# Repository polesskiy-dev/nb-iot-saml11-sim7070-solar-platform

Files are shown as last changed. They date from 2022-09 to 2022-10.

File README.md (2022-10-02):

# NB IoT platform

### Based on:
* MCU: Microchip SAML11
* GSM, GPS: SIMCom SIM7070
* Power: 2V Solar panel or DC 5V, MPPT harvester, 1xLiFePO4 18650 

### Hardware features:
* Sensors IN: 
  * 2xPulse, 3V3-48V tolerant, optocouple galvanic isolation. Supports NPN, PNP
  * 1xADC, 1V2-48V tolerant
  * 2x4 wires: USART, LIN client, I2C client/host, SPI client/host, RS485 (3V3), 3V3-5V tolerant, buffered
* Sensors power OUT: 3V3, 12V or self-powered
* Power: 1V5-2V5 Solar MPPT Harvester or DC 5V, LiFePO4/Li-ion charger, reverse polarity protection
* [ ] power consumption values plot

### Software features:
* [ ] AWS integration
* [ ] MQTTs
* [ ] I2C BME280 temperature/humidity/pressure sensor support

### Schematics:


### Board:

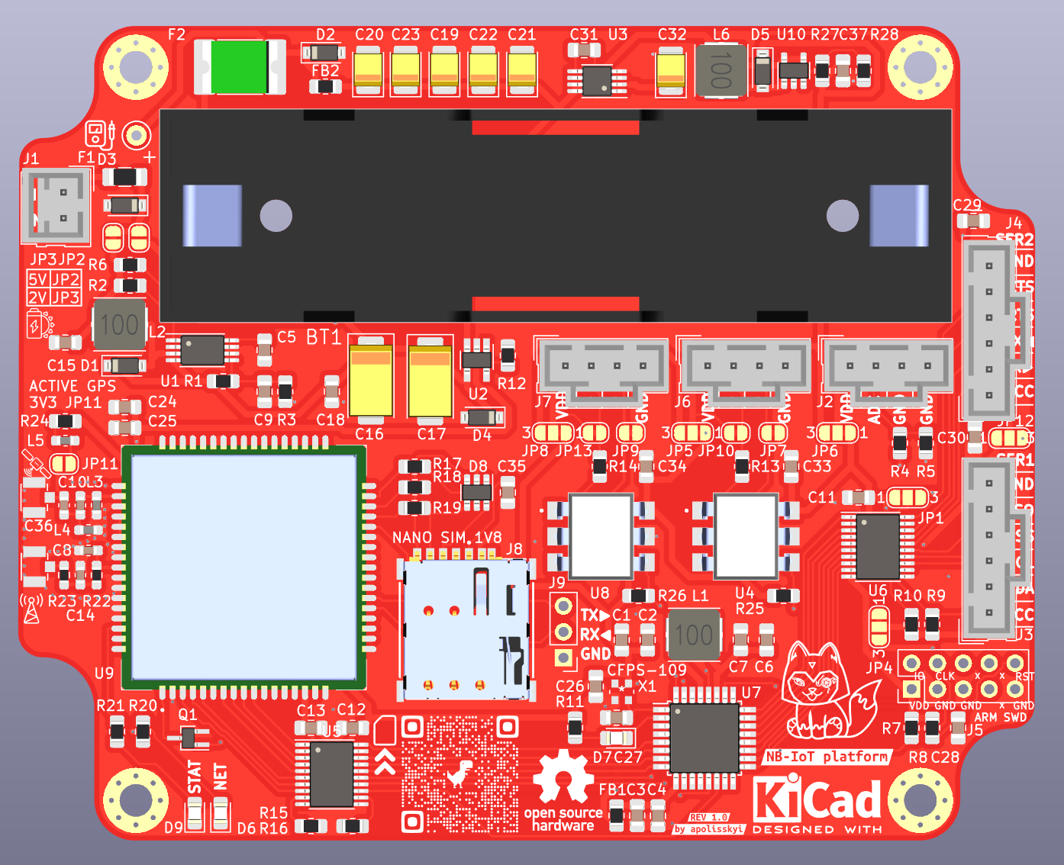
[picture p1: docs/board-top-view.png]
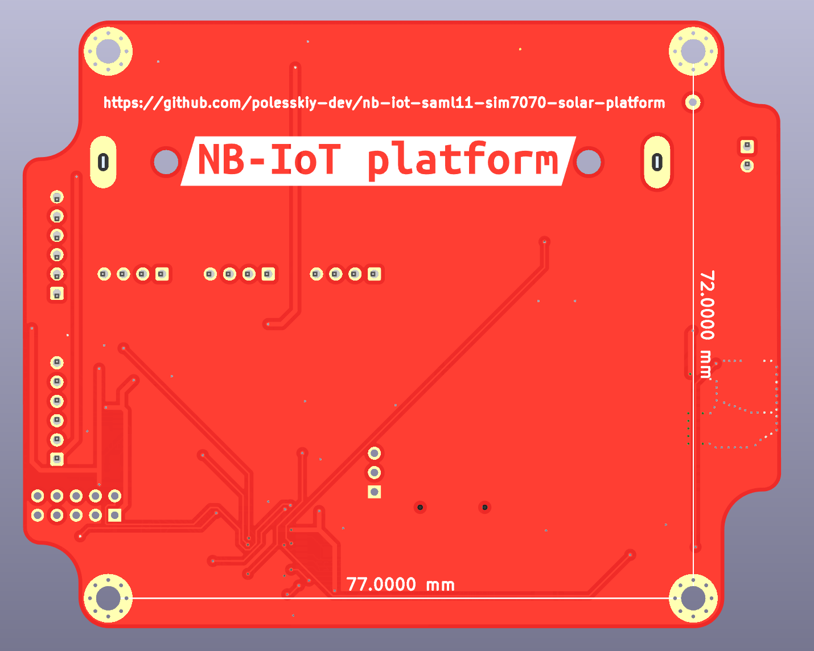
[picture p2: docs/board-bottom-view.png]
 

### Enclosure:
Gainta G113

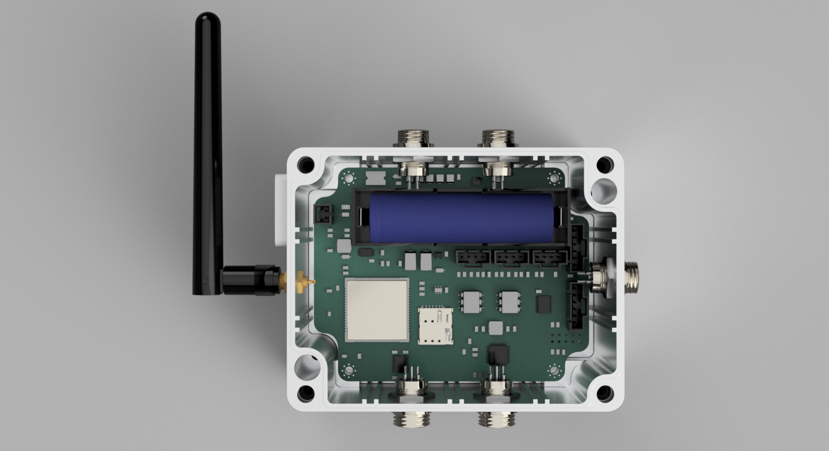
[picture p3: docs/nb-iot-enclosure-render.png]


### BOM:
[Interactive BOM](https://polesskiy-dev.github.io/nb-iot-saml11-sim7070-solar-platform/bom/ibom.html)

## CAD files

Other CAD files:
hardware/nb-iot-saml11-sim7070-solar-platform-G113-v17.f3d

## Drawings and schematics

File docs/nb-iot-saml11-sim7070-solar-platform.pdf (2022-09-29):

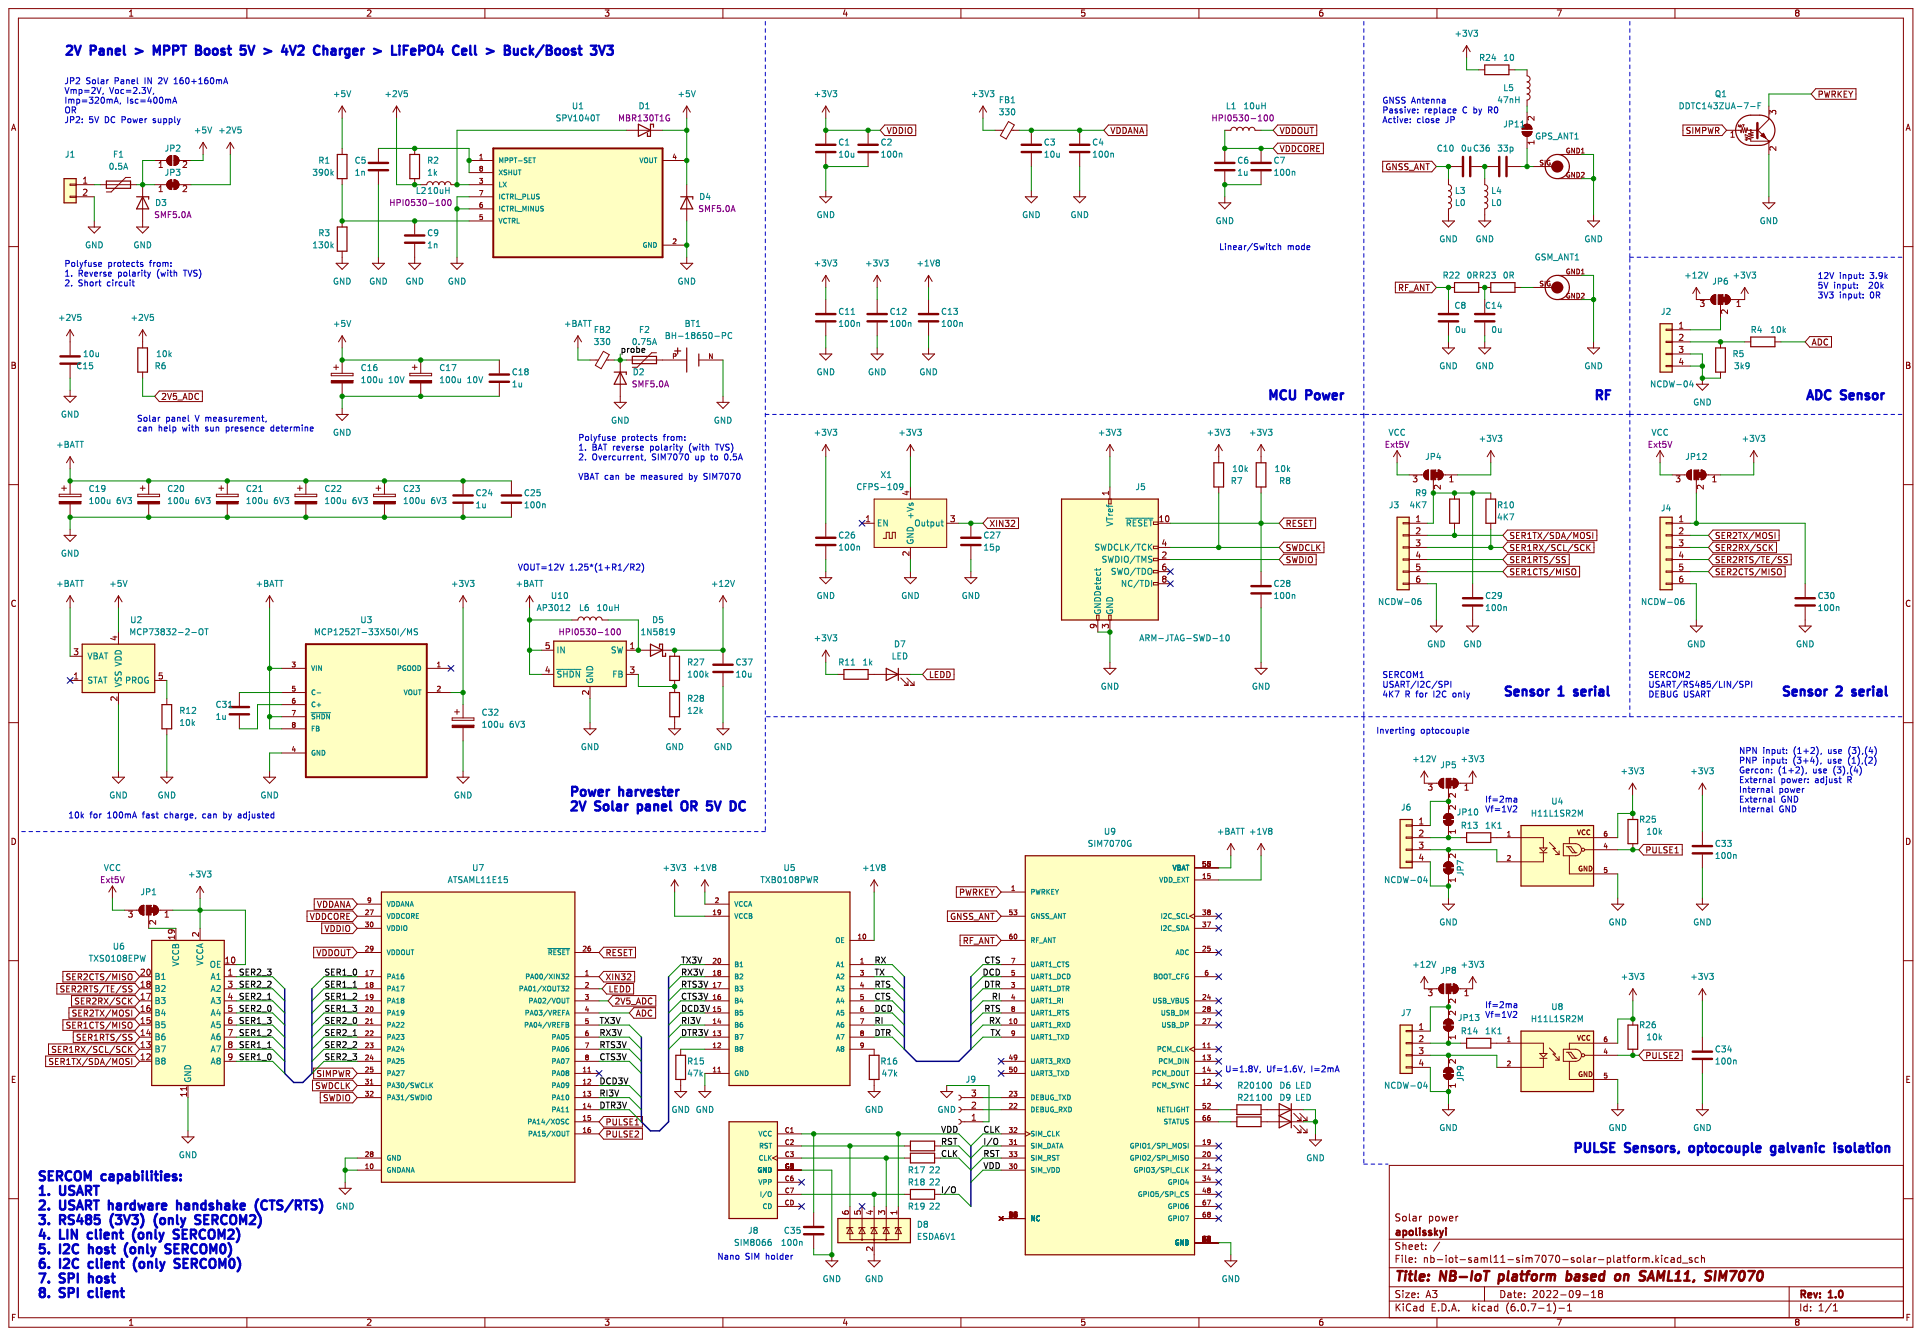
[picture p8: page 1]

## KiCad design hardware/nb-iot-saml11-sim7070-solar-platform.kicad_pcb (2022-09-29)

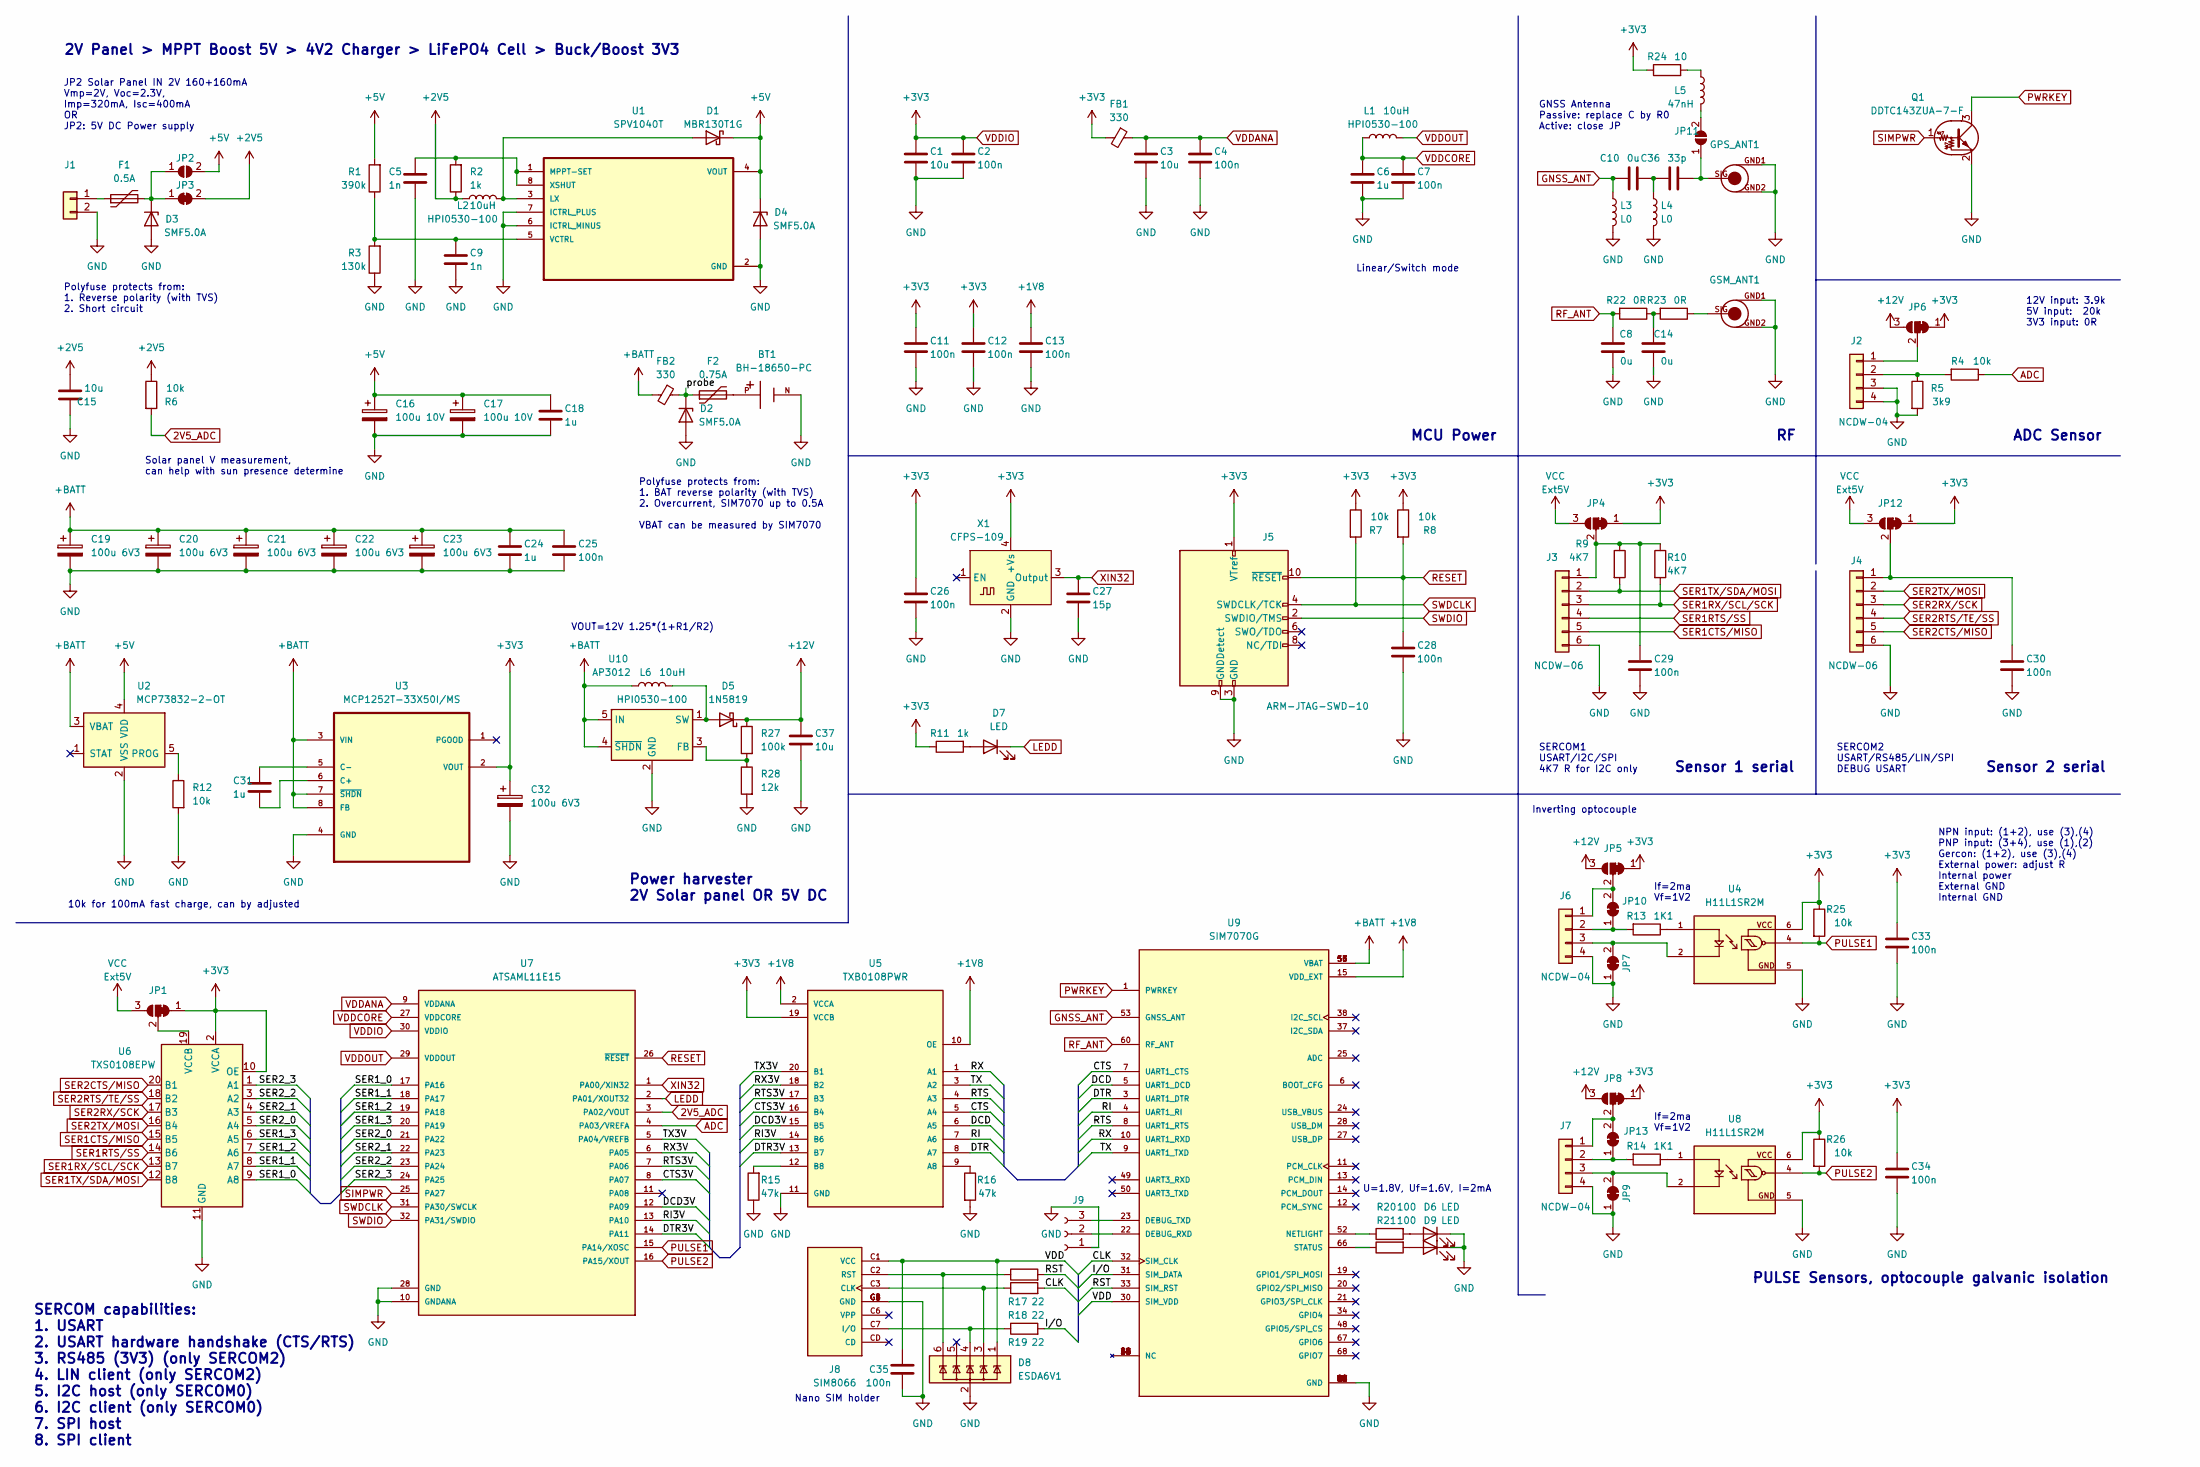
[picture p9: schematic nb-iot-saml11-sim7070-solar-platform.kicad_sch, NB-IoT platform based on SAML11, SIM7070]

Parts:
BT1: BH-18650-PC; BAT_BH-18650-PC; PARTREV 05/17/19
C1, C3, C15, C37: 10u; C_0805_2012Metric_Pad1.18x1.45mm_HandSolder
C2, C4, C7, C11, C12, C13, C25, C26, C28, C29, C30, C33, C34, C35: 100n; C_0805_2012Metric_Pad1.18x1.45mm_HandSolder
C5, C9: 1n; C_0805_2012Metric_Pad1.18x1.45mm_HandSolder
C6, C18, C24, C31: 1u; C_0805_2012Metric_Pad1.18x1.45mm_HandSolder
C8, C10, C14: 0u; C_0603_1608Metric_Pad1.08x0.95mm_HandSolder
C16, C17: 100u 10V; CP_EIA-7343-31_Kemet-D_Pad2.25x2.55mm_HandSolder; PARTNUMBER T491D107K010AT
C19, C20, C21, C22, C23, C32: 100u 6V3; CP_EIA-3528-21_Kemet-B_Pad1.50x2.35mm_HandSolder; PARTNUMBER TAJB107K006RNJ
C27: 15p; C_0805_2012Metric_Pad1.18x1.45mm_HandSolder
C36: 33p; C_0603_1608Metric_Pad1.08x0.95mm_HandSolder
D1: D_Schottky; D_SOD-123; PARTNUMBER MBR130T1G
D2, D3, D4: D_Zener; D_SOD-123; PARTNUMBER SMF5.0A
D5: 1N5819; D_SOD-123
D6, D7, D9: LED; LED_0805_2012Metric_Pad1.15x1.40mm_HandSolder
D8: ESDA6V1; SOT-23-6
F1: 0.5A; Fuse_1206_3216Metric_Pad1.42x1.75mm_HandSolder; PARTNUMBER SMD1206P050TF
F2: 0.75A; Fuse_2920_7451Metric_Pad2.10x5.45mm_HandSolder; PARTNUMBER 0ZCF0075FF2C
FB1, FB2: 330; R_0805_2012Metric_Pad1.20x1.40mm_HandSolder
GPS_ANT1: U.FL-R-SMT-1; GHI-CONNECTORS_U.FL-R-SMT-1
GSM_ANT1: U.FL-R-SMT-1; GHI-CONNECTORS_U.FL-R-SMT-1
J1: Conn_01x02; Molex_SL_171971-0002_1x02_P2.54mm_Vertical
J2, J6, J7: NCDW-04; Molex_SL_171971-0004_1x04_P2.54mm_Vertical
J3, J4: NCDW-06; Molex_SL_171971-0006_1x06_P2.54mm_Vertical
J5: ARM-JTAG-SWD-10; PinHeader_2x05_P2.54mm_Vertical
J8: SIM8066; GCT_SIM8066-6-1-14-01-A_REVA; PARTREV REVA
J9: Conn_01x03_Female; PinHeader_1x03_P2.54mm_Vertical
JP1, JP4, JP5, JP6, JP8, JP12: SolderJumper_3_Bridged12; SolderJumper-3_P1.3mm_Bridged12_RoundedPad1.0x1.5mm_NumberL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
JP2, JP11: SolderJumper_2_Open; SolderJumper-2_P1.3mm_Open_RoundedPad1.0x1.5mm
JP3, JP7, JP9, JP10, JP13: SolderJumper_2_Bridged; SolderJumper-2_P1.3mm_Bridged_RoundedPad1.0x1.5mm
L1, L2, L6: 10uH; L_Taiyo-Yuden_MD-5050; PARTNUMBER HPI0530-100
L3, L4: L0; L_0603_1608Metric_Pad1.05x0.95mm_HandSolder
L5: 47nH; L_0603_1608Metric_Pad1.05x0.95mm_HandSolder
Q1: DDTC143ZUA-7-F; SOT-323_SC-70_Handsoldering
R1: 390k; R_0805_2012Metric_Pad1.20x1.40mm_HandSolder
R2, R11: 1k; R_0805_2012Metric_Pad1.20x1.40mm_HandSolder
R3: 130k; R_0805_2012Metric_Pad1.20x1.40mm_HandSolder
R4, R6, R7, R8, R12, R25, R26: 10k; R_0805_2012Metric_Pad1.20x1.40mm_HandSolder
R5: 3k9; R_0805_2012Metric_Pad1.20x1.40mm_HandSolder
R9, R10: 4K7; R_0805_2012Metric_Pad1.20x1.40mm_HandSolder
R13, R14: 1K1; R_0805_2012Metric_Pad1.20x1.40mm_HandSolder
R15, R16: 47k; R_0805_2012Metric_Pad1.20x1.40mm_HandSolder
R17, R18, R19: 22; R_0805_2012Metric_Pad1.20x1.40mm_HandSolder
R20, R21: 100; R_0805_2012Metric_Pad1.20x1.40mm_HandSolder
R22, R23: 0R; R_0603_1608Metric_Pad0.98x0.95mm_HandSolder
R24: 10; R_0805_2012Metric_Pad1.20x1.40mm_HandSolder
R27: 100k; R_0805_2012Metric_Pad1.20x1.40mm_HandSolder
R28: 12k; R_0805_2012Metric_Pad1.20x1.40mm_HandSolder
U1: SPV1040T; TSSOP-8_4.4x3mm_P0.65mm; PARTREV 7
U2: MCP73832-2-OT; SOT-23-5_HandSoldering
U3: MCP1252T-33X50I/MS; MSOP-8_3x3mm_P0.65mm; MPN MCP1252T-33X50I/MS
U4, U8: H11L1SR2M; IC_H11L1SR2M; PARTREV 3
U5: TXB0108PWR; TSSOP-20_4.4x6.5mm_P0.65mm; PARTREV H
U6: TXS0108EPW; TSSOP-20_4.4x6.5mm_P0.65mm
U7: ATSAML11E15; TQFP-32_7x7mm_P0.8mm; PARTREV G
U9: SIM7070G; MODULE_SIM7070G; PARTREV V1.03
U10: AP3012; SOT-23-5
X1: CFPS-109

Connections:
2V5_ADC: R6.2, U7.3 (PA02/VOUT)
+1V8: C13.1, U5.2 (VCCA), U5.10 (OE), U9.15 (VDD_EXT)
+2V5: C15.2, JP3.2 (B), L2.1, R2.1, R6.1
+5V: C16.1, C17.1, C18.1, D1.1 (K), D4.1 (K), JP2.2 (B), R1.2, U1.4 (VOUT), U2.4 (VDD)
+12V: C37.1, D5.1 (K), JP5.3 (B), JP6.3 (B), JP8.3 (B), R27.1
+BATT: C19.1, C20.1, C21.1, C22.1, C23.1, C24.1, C25.1, FB2.2, L6.1, U2.3 (VBAT), U3.3 (VIN), U3.7 (~SHDN), U3.8 (FB), U9.55 (VBAT), U9.56 (VBAT), U9.57 (VBAT), U10.4 (~SHDN), U10.5 (IN)
/CLK: R18.2, U9.32 (SIM_CLK)
/CTS: U5.5 (A4), U9.7 (UART1_CTS)
/CTS3V: U5.16 (B4), U7.8 (PA07)
/DCD: U5.6 (A5), U9.5 (UART1_DCD)
/DCD3V: U5.15 (B5), U7.12 (PA09)
/DTR: U5.8 (A7), U9.3 (UART1_DTR)
/DTR3V: U5.13 (B7), U7.14 (PA11)
/I/O: R19.2, U9.31 (SIM_DATA)
/RI: U5.7 (A6), U9.4 (UART1_RI)
/RI3V: U5.14 (B6), U7.13 (PA10)
/RST: R17.2, U9.33 (SIM_RST)
/RTS: U5.4 (A3), U9.8 (UART1_RTS)
/RTS3V: U5.17 (B3), U7.7 (PA06)
/RX: U5.1 (A1), U9.10 (UART1_RXD)
/RX3V: U5.18 (B2), U7.6 (PA05)
/SER1_0: U6.9 (A8), U7.17 (PA16)
/SER1_1: U6.8 (A7), U7.18 (PA17)
/SER1_2: U6.7 (A6), U7.19 (PA18)
/SER1_3: U6.6 (A5), U7.20 (PA19)
/SER2_0: U6.5 (A4), U7.21 (PA22)
/SER2_1: U6.4 (A3), U7.22 (PA23)
/SER2_2: U6.3 (A2), U7.23 (PA24)
/SER2_3: U6.1 (A1), U7.24 (PA25)
/TX: U5.3 (A2), U9.9 (UART1_TXD)
/TX3V: U5.20 (B1), U7.5 (PA04/VREFB)
/VDD: C35.1, D8.1 (IO1), J8.C1 (VCC), U9.30 (SIM_VDD)
/probe: D2.1 (K), F2.1, FB2.1; also elsewhere on the board
ADC: R4.1, U7.4 (PA03/VREFA)
GND: BT1.N, C1.2, C2.2, C3.2, C4.2, C5.2, C6.2, C7.2, C8.1, C9.2, C11.2, C12.2, C13.2, C14.1, C15.1, C16.2, C17.2, C18.2, C19.2, C20.2, C21.2, C22.2, C23.2, C24.2, C25.2, C26.2, C27.2, C28.2, C29.2, C30.2, C32.2, C33.2, C34.2, C35.2, C37.2, D2.2 (A), D3.2 (A), D4.2 (A), D6.1 (K), D8.2 (GND), D9.1 (K), GPS_ANT1.GND1, GPS_ANT1.GND2, GSM_ANT1.GND1, GSM_ANT1.GND2, J1.2, J2.3, J2.4, J3.6, J4.6, J5.3 (GND), J5.5 (GND), J5.9 (GNDDetect), J6.4, J7.4, J8.C5 (GND), J8.G1 (GND), J8.G2 (GND), J8.G3 (GND), J8.G4 (GND), J9.1, JP7.1 (A), JP9.1 (A), L3.2, L4.2, Q1.2 (E), R3.1, R5.2, R12.2, R15.1, R16.2, R28.2, U1.2 (GND), U1.6 (ICTRL_MINUS), U1.7 (ICTRL_PLUS), U2.2 (VSS), U3.4 (GND), U4.5, U5.11 (GND), U6.11 (GND), U7.10 (GNDANA), U7.28 (GND), U8.5, U9.2 (GND), U9.17 (GND), U9.18 (GND), U9.29 (GND), U9.39 (GND), U9.45 (GND), U9.46 (GND), U9.54 (GND), U9.58 (GND), U9.59 (GND), U9.61 (GND), U9.62 (GND), U9.63 (GND), U9.64 (GND), U9.65 (GND), U10.2 (GND), X1.2 (GND); also elsewhere on the board
GNSS_ANT: C10.2, L3.1, U9.53 (GNSS_ANT)
LEDD: D7.1 (K), U7.2 (PA01/XOUT32)
unnamed: BT1.P, F2.2
unnamed: C5.1, R2.2, U1.1 (MPPT-SET), U1.8 (XSHUT)
unnamed: C9.1, R1.1, R3.2, U1.5 (VCTRL)
unnamed: C10.1, C36.2, L4.1
unnamed: C14.2, R22.1, R23.2
unnamed: C29.1, J3.1, JP4.2 (C), R9.1, R10.1
unnamed: C30.1, J4.1, JP12.2 (C)
unnamed: C31.1, U3.5 (C-)
unnamed: C31.2, U3.6 (C+)
unnamed: C36.1, GPS_ANT1.SIG, JP11.1 (A)
unnamed: D1.2 (A), L2.2, U1.3 (LX)
unnamed: D3.1 (K), F1.2, JP2.1 (A), JP3.1 (A)
unnamed: D5.2 (A), L6.2, U10.1 (SW)
unnamed: D6.2 (A), R20.2
unnamed: D7.2 (A), R11.2
unnamed: D8.3 (IO2), J8.C3 (CLK), R18.1
unnamed: D8.4 (IO3), J8.C7 (I/O), R19.1
unnamed: D8.6 (IO5), J8.C2 (RST), R17.1
unnamed: D9.2 (A), R21.2
unnamed: F1.1, J1.1
unnamed: GSM_ANT1.SIG, R23.1
unnamed: J2.1, JP6.2 (C)
unnamed: J2.2, R4.2, R5.1
unnamed: J6.1, JP5.2 (C), JP10.2 (B)
unnamed: J6.2, JP10.1 (A), R13.2
unnamed: J6.3, JP7.2 (B), U4.2
unnamed: J7.1, JP8.2 (C), JP13.2 (B)
unnamed: J7.2, JP13.1 (A), R14.2
unnamed: J7.3, JP9.2 (B), U8.2
unnamed: J9.2, U9.22 (DEBUG_RXD)
unnamed: J9.3, U9.23 (DEBUG_TXD)
unnamed: JP1.2 (C), U6.19 (VCCB)
unnamed: JP11.2 (B), L5.2
unnamed: L5.1, R24.2
unnamed: R12.1, U2.5 (PROG)
unnamed: R13.1, U4.1
unnamed: R14.1, U8.1
unnamed: R15.2, U5.12 (B8)
unnamed: R16.1, U5.9 (A8)
unnamed: R20.1, U9.52 (NETLIGHT)
unnamed: R21.1, U9.66 (STATUS)
unnamed: R27.2, R28.1, U10.3 (FB)
PULSE1: R25.2, U4.4, U7.15 (PA14/XOSC)
PULSE2: R26.2, U7.16 (PA15/XOUT), U8.4
PWRKEY: Q1.3 (C), U9.1 (PWRKEY)
RESET: C28.1, J5.10 (~RESET), R8.2, U7.26 (~RESET)
RF_ANT: C8.2, R22.2, U9.60 (RF_ANT)
SER1CTS/MISO: J3.5, U6.15 (B5)
SER1RTS/SS: J3.4, U6.14 (B6)
SER1RX/SCL/SCK: J3.3, R10.2, U6.13 (B7)
SER1TX/SDA/MOSI: J3.2, R9.2, U6.12 (B8)
SER2CTS/MISO: J4.5, U6.20 (B1)
SER2RTS/TE/SS: J4.4, U6.18 (B2)
SER2RX/SCK: J4.3, U6.17 (B3)
SER2TX/MOSI: J4.2, U6.16 (B4)
SIMPWR: Q1.1 (B), U7.25 (PA27)
SWDCLK: J5.4 (SWDCLK/TCK), R7.2, U7.31 (PA30/SWCLK)
SWDIO: J5.2 (SWDIO/TMS), U7.32 (PA31/SWDIO)
VCC: JP1.3 (B), JP4.3 (B), JP12.3 (B)
VDDANA: C3.1, C4.1, FB1.1, U7.9 (VDDANA)
VDDCORE: C6.1, C7.1, L1.1, U7.27 (VDDCORE)
VDDIO: C1.1, C2.1, C11.1, C12.1, C26.1, C32.1, C33.1, C34.1, FB1.2, J5.1 (VTref), JP1.1 (A), JP4.1 (A), JP5.1 (A), JP6.1 (A), JP8.1 (A), JP12.1 (A), R7.1, R8.1, R11.1, R24.1, R25.1, R26.1, U3.2 (VOUT), U4.6, U5.19 (VCCB), U6.2 (VCCA), U6.10 (OE), U7.30 (VDDIO), U8.6, X1.4 (+Vs)
VDDOUT: L1.2, U7.29 (VDDOUT)
XIN32: C27.1, U7.1 (PA00/XIN32), X1.3 (Output)

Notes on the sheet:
If=2ma Vf=1V2
ADC Sensor
Polyfuse protects from: 1. BAT reverse polarity (with TVS) 2. Overcurrent, SIM7070 up to 0.5A VBAT can be measured by SIM7070
GNSS Antenna Passive: replace C by R0 Active: close JP
10k for 100mA fast charge, can by adjusted
U=1.8V, Uf=1.6V, I=2mA
Power harvester 2V Solar panel OR 5V DC
PULSE Sensors, optocouple galvanic isolation
Sensor 1 serial
MCU Power
Linear/Switch mode
12V input: 3.9k 5V input: 20k 3V3 input: 0R
VOUT=12V 1.25*(1+R1/R2)
2V Panel > MPPT Boost 5V > 4V2 Charger > LiFePO4 Cell > Buck/Boost 3V3
SERCOM1 USART/I2C/SPI 4K7 R for I2C only
SERCOM capabilities: 1. USART 2. USART hardware handshake (CTS/RTS) 3. RS485 (3V3) (only SERCOM2) 4. LIN client (only SERCOM2) 5. I2C host (only SERCOM0) 6. I2C client (only SERCOM0) 7. SPI host 8. SPI client
SERCOM2 USART/RS485/LIN/SPI DEBUG USART
Nano SIM holder
JP2 Solar Panel IN 2V 160+160mA Vmp=2V, Voc=2.3V, Imp=320mA, Isc=400mA OR JP2: 5V DC Power supply
Polyfuse protects from: 1. Reverse polarity (with TVS) 2. Short circuit
NPN input: (1+2), use (3),(4) PNP input: (3+4), use (1),(2) Gercon: (1+2), use (3),(4) External power: adjust R Internal power External GND Internal GND
Sensor 2 serial
Inverting optocouple
Solar panel V measurement, can help with sun presence determine

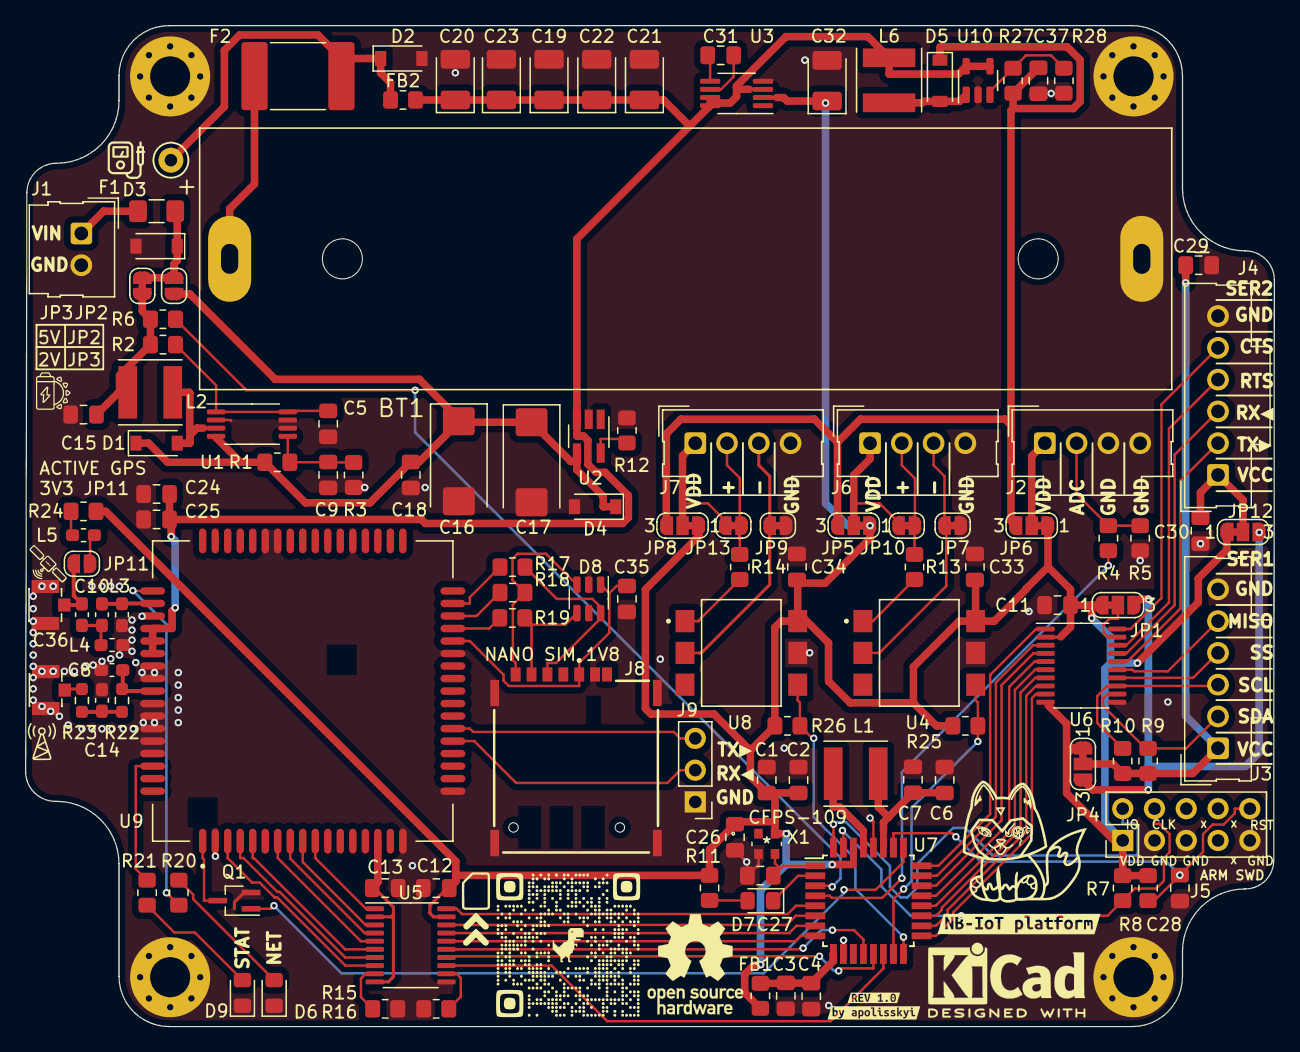
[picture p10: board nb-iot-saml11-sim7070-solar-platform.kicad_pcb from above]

Board: 2 copper layers, 99.8 x 80.0 mm, 140 parts (0 on the bottom side), 101 nets.

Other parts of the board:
G2, G3, G4, G5, G6, G7, G8, G100: LOGO
REF0: TestPoint_Keystone_5000-5004_Miniature
REF1: OSHW-Logo_7.5x8mm_SilkScreen
REF2: KiCad-Logo2_5mm_SilkScreen
REF6, REF6#2, REF6#3, REF6#4: MountingHole_3.2mm_M3_Pad_Via
kibuzzard-63309E1C: G***; kibuzzard-63309E1C
kibuzzard-6330987C: G***; kibuzzard-6330987C
kibuzzard-63309844: G***; kibuzzard-63309844
kibuzzard-63309884: G***; kibuzzard-63309884

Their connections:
/probe: REF0.1; also elsewhere on the board
GND: REF6.1, REF6#2.1, REF6#3.1, REF6#4.1; also elsewhere on the board

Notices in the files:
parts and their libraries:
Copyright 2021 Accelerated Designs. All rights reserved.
